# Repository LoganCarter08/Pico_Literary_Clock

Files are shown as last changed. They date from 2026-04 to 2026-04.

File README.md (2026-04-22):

# DIY Literary Clock Running on a Raspberry Pi Pico W

Display a book quote for each minute of the day!

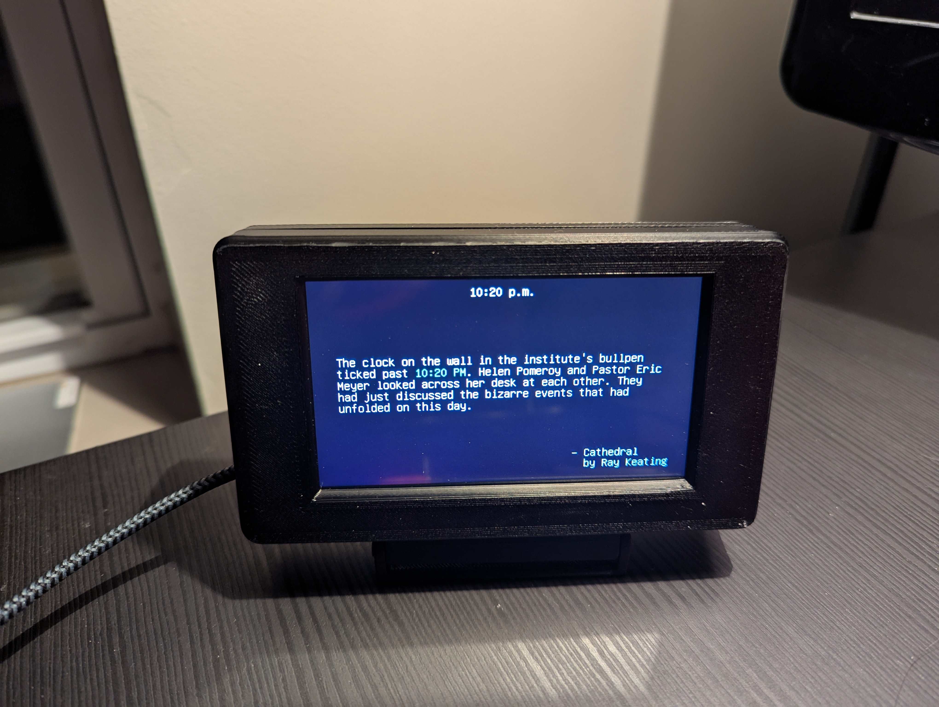
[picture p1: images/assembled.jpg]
on image

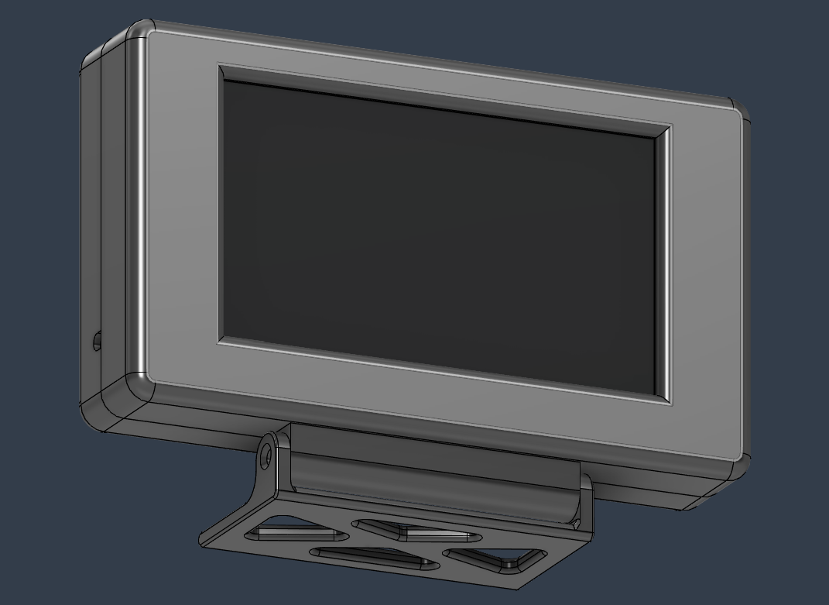
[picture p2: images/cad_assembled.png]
cad assembled


Quotes (litclock_annotated.csv) were sourced from https://github.com/JohannesNE/literature-clock/tree/master

## Hardware and Tools Required:

1. Pico Pi 2 W. Likely a Pico Pi W would work, but I have only tested a 2. A W model is needed for a wifi connection.
2. A display. [This one](https://www.buydisplay.com/4-3-inch-tft-lcd-display-capacitive-touchscreen-ra8875-controller) was used. A touchscreen version was selected for this, but they likely have cheaper ones without touchscreen capabilities.
   1. If you use the one linked I used the following configuration:
      1. Interface: Pin Header Connection-4-Wire SPI
      2. Power Supply: VDD=5.0V
      3. Font Chip: ER3301-1
   2. If you use a different one you will need to modify the 3D models and likely the code

3. 3D printer or ability to get 3D printed parts
4. Soldering iron
5. Solder
6. Wire
7. Wire Strippers
8. [3mm x 20mm flat chamfer headed bolts](https://www.amazon.com/Hoomuy-100pcs-Socket-Countersunk-Threaded/dp/B0GDWH9DZK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)
9. [3mm x 8mm flat chamfer headed bolts](https://www.amazon.com/DTGN-M3-0-5x8mm-Socket-Screws-Countersunk/dp/B0CQ1VJTMK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)
10. [3mm threaded heat inserts](https://www.amazon.com/Ktehloy-Threaded-Printing-Components-M3x4x5mm/dp/B0CLKCQ2SH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)
11. [2mm x 6mm bolts](https://www.amazon.com/M2-0-4-Socket-Machine-Countersunk-Quantity/dp/B0CG1SXGCN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)
12. [2mm nuts](https://www.amazon.com/pouilzx-Carbon-Steel-Hexagon-200pcs/dp/B0CMG7Q27P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)
13. Micro USB cable
14. USB power supply. Must match the other end of the micro USB cable.

## Software Instructions:

1. [Configure your Pico](https://learn.adafruit.com/getting-started-with-raspberry-pi-pico-circuitpython/circuitpython) to use CircuitPython. Be sure to select the correct uf2 file for your board. The link in the guide will just take you to the original Pico.
1. Go to [Adafruit](https://accounts.adafruit.com/) and create an account.
1. Sign into [Adafruit IO](io.adafruit.com) with your Adafruit account.
1. Click My Key on the top bar.
1. Open circuit_python_files/settings.toml
1. Replace ADAFRUIT_AIO_USERNAME and ADAFRUIT_AIO_KEY with your Adafruit account details.
1. Use the [TZ identifier values on Wikipedia](https://en.wikipedia.org/wiki/List_of_tz_database_time_zones) to set your timezone.
1. Set CIRCUITPY_WIFI_SSID as your wifi name.
1. Set CIRCUITPY_WIFI_PASSWORD as your wifi password.
1. Change the rest of the settings in settings.toml to match your preferences. Descriptions of each setting can be found below.

   Note: Some sample colors are provided. More can be added within the COLORS dict in code.py. They are in RGB format and can be modified or more can be added for your needs.

1. Make sure you have Python installed on your computer. Latest version is recommended.
1. Open a terminal and navigate to the folder containing these files and run `python .\csv_to_json.py`
1. Make sure Circuit Python is installed on your Pico Pi
1. Connect your Pico to your computer
1. Upload the contents of circuit_python_files to your Pico. This will take a while.

## settings.toml

The following settings are for you to be able to configure certain parts of the display without changing actual code.

| Setting | Description | Accepted Values/Type |
| --- | --- | --- |
| CIRCUITPY_WIFI_SSID | Name of your wifi. | String |
| CIRCUITPY_WIFI_PASSWORD | Password for your wifi | String |
| ADAFRUIT_AIO_USERNAME | Username for your Adafruit AIO account. | String |
| ADAFRUIT_AIO_KEY | Access key for your Adafruit AIO account. | String |
| TIMEZONE | Timezone you live in. [List of timezones.](https://en.wikipedia.org/wiki/List_of_tz_database_time_zones) | String |
| DISPLAY_MERIDIEM | Display a.m. or p.m. in the time at the top of the screen. Is not applied if using military time. | String as "true" or "false" |
| USE_MILITARY_TIME | Display time at the top of the screen in military time instead of 12 hour. | String as "true" or "false" |
| SCREEN_OFF_TIME | Time the screen should turn off. This will save power and increase the lifespan of your screen. | String of array in format of "[hour, minute]" |
| SCREEN_ON_TIME | Time the screen should turn on. | String of array in format of "[hour, minutes]" |
| BACKGROUND_COLOR | Color to choose for the background of the screen. | String options: "BLACK", "RED", "BLUE", "GREEN", "YELLOW", "CYAN", "MAGENTA", "WHITE" |
| TEXT_COLOR | Color for any text that is not the time of day in the quote. | String options: "BLACK", "RED", "BLUE", "GREEN", "YELLOW", "CYAN", "MAGENTA", "WHITE" |
| HIGHLIGHT_COLOR | Color for the time in the quote. | String options: "BLACK", "RED", "BLUE", "GREEN", "YELLOW", "CYAN", "MAGENTA", "WHITE" |

## Assembly Instructions:

1. Print all of the pieces in the 3d_model_files folder
2. Add the heat insert threads into each of the 4 corners of the front piece
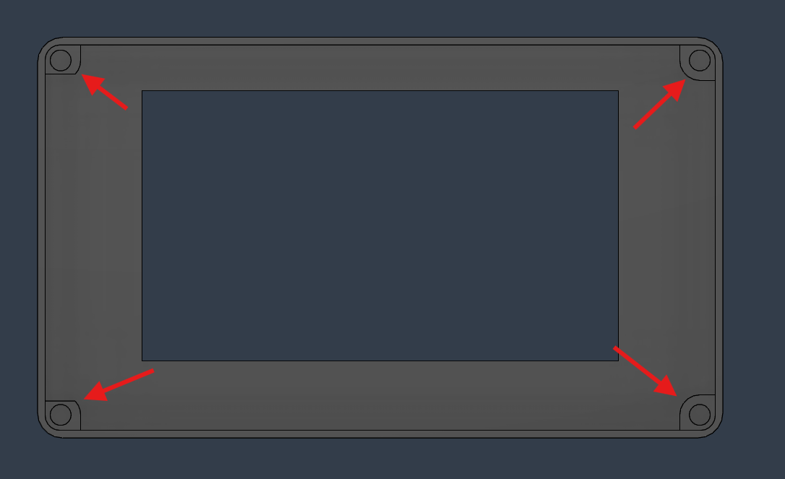
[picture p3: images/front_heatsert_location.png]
front heatsert locations
   
3. Heat insert threads into all 4 holes on the base mount
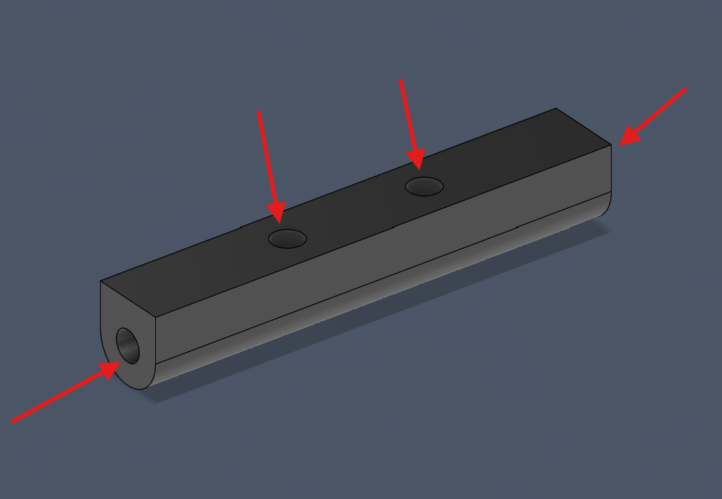
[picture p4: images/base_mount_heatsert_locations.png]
base heatsert locations
   
4. Sand down the corners of the screen to fit in the 3D printed case. The corners just need to be rounded to match the metal around the mounting hole.
5. Bolt the base mount to the front cover.
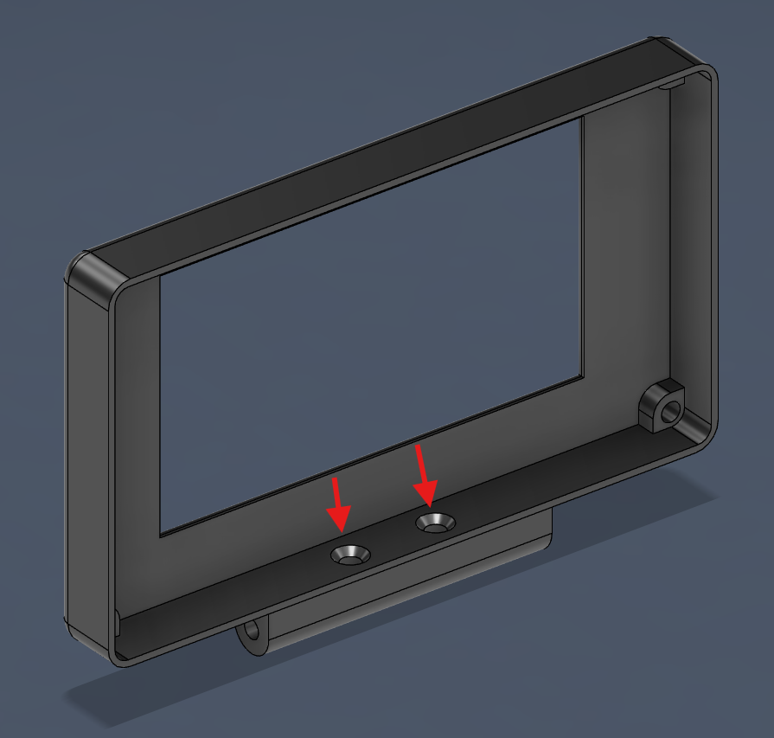
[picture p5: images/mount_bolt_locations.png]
base to front bolt locations
   
6. Insert the screen into the front cover.
7. Bolt the pico onto the pi mount piece using 4 M2 bolts and nuts. The pico should go on the smooth side of the plate. The side with the offset feet will sit on the screen. The Pico's USB port should face away from the GPIO pins on the screen.
8. Sit the pi mount plate onto the screen so that the 4 holes align.
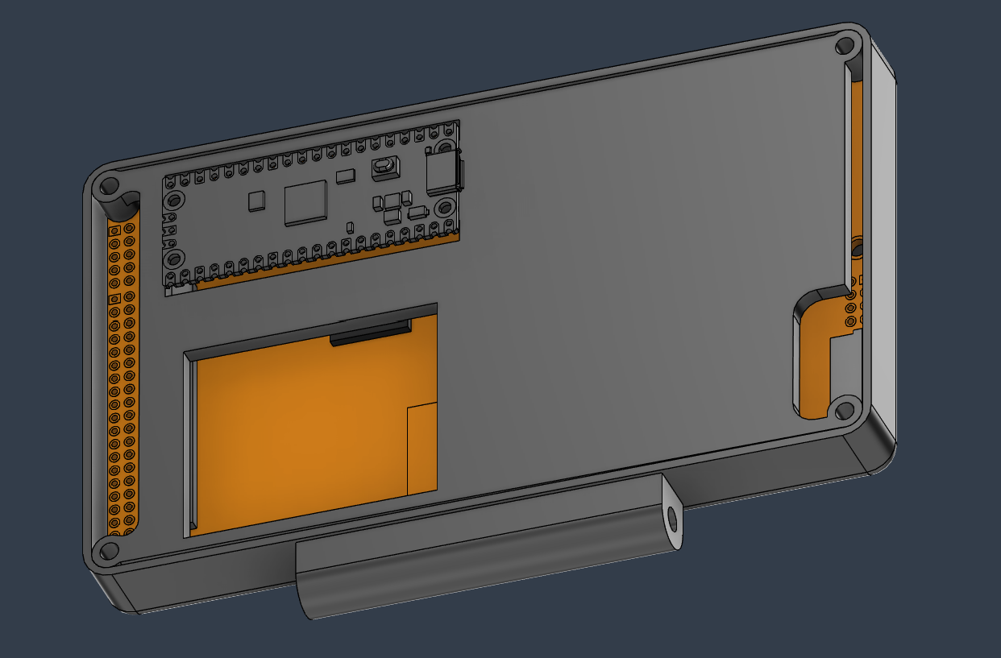
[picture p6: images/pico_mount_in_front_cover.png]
pico in front cover
   
9. Solder wires from the pi to the screen. Pinout information can be found below.
10. Plug the USB cable into the pi
11. Sit the back cover over the pi and screen where the slot in the cover allows for the USB cable to exit the bottom left (left when viewing from the front) of the case
12. Bolt the base plate onto the base mount and snug the screws when the desired any is set
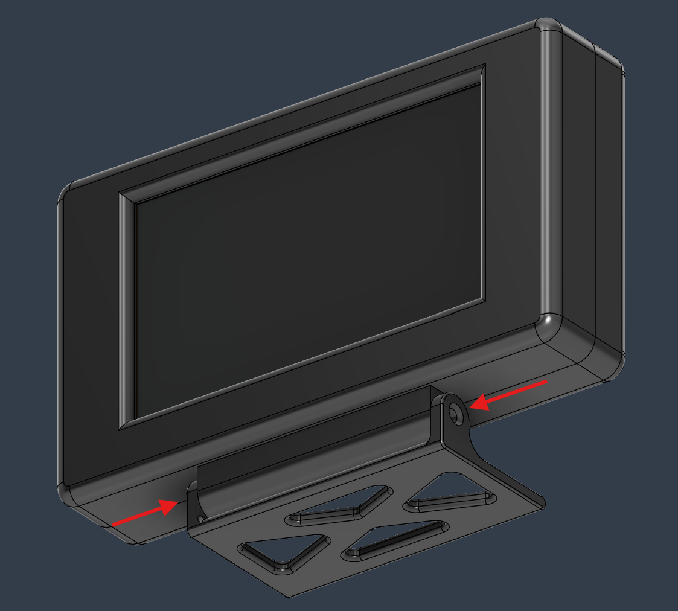
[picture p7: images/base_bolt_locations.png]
base plate bolt locations
    
13. Plug the USB cable into the power supply and wait for the screen to startup. This may take a few seconds depending on how quickly it can connect to your network.

## Pinouts:

[Screen doc with pin locations](https://www.buydisplay.com/download/manual/ER-TFTM043A2-3_Datasheet.pdf).

| Pico Pin | Screen Pin # | Description |
| --- | --- | --- |
| GP21 | 5 | CS |
| GP22 | 11 | Reset |
| GP1 | 10 | Int |
| GP18 | 8 | SCLK |
| GP19 | 7 | Pico MOSI |
| GP16 | 6 | Pico MISO |

## Other Notes:

- Other microcontroller boards than the Pico Pi W can be used. The 3D models will need updated and likely some code changes to support the correct pinout. You will also be limited to storage space as the quote files take up a lot of space.
- A Pico W is required because the device needs to connect to the internet to keep the clock synchronized as there tends to be some time drift relying on internal time keeping.
- If you want to add/edit/delete any quotes you can edit the litclock_annotated.csv file, delete the quotes off the pico, and then load the new quotes from the circuit_python_files/lib/quotes folder. Otherwise you may get errors about not enough storage space.
- A few times of the day currently do not have quotes. If you find any please feel free to let me know and I can update the file with them. Current 11:46, 12:31, 13:36, and 18:44 are missing.

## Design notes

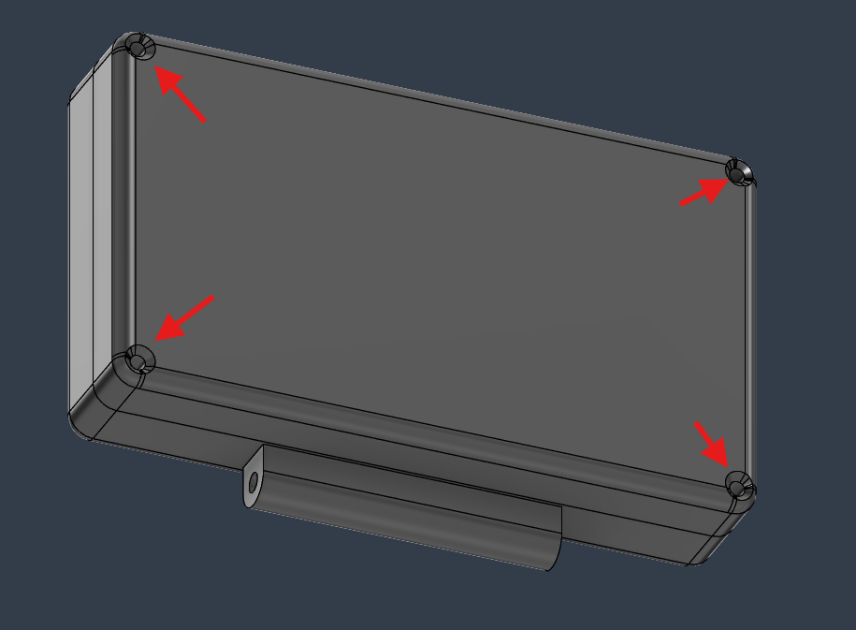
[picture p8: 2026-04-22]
images/back_cover_bolt_locations.png

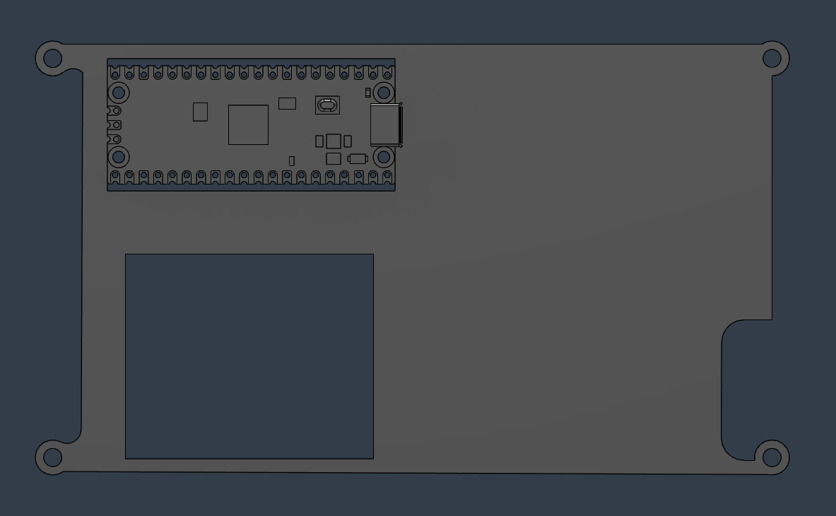
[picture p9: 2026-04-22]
images/pico_mount_orientation.png

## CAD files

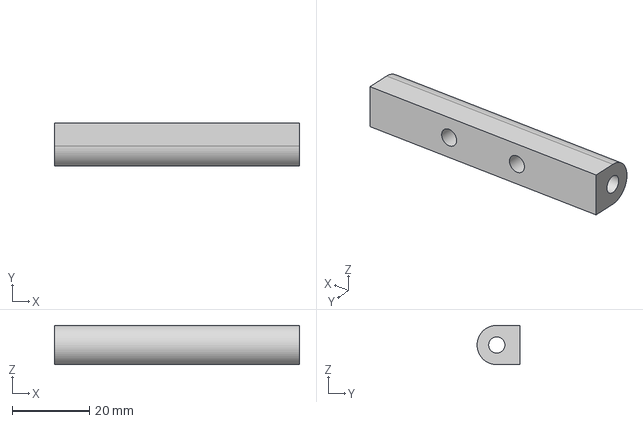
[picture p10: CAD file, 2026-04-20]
3d_model_files/base_mount.step
63.5 x 11.1 x 10.2 mm

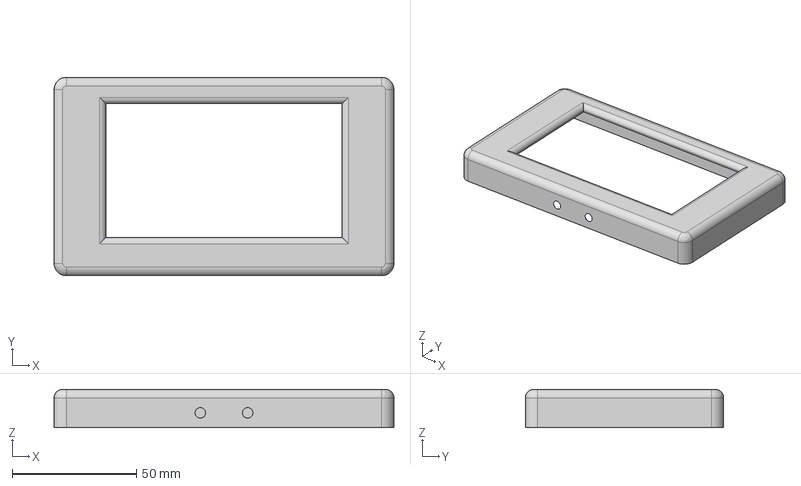
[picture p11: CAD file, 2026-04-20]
3d_model_files/front.step
136.7 x 79.8 x 15.4 mm

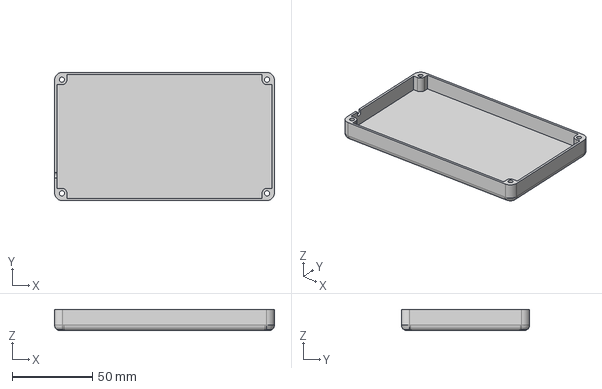
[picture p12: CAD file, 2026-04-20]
3d_model_files/back.step
136.7 x 79.8 x 13.2 mm

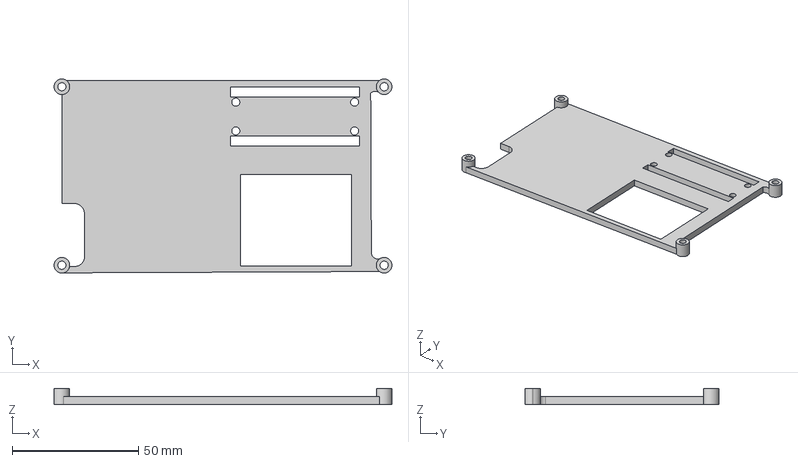
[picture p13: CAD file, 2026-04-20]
3d_model_files/pi_mount.step
133.7 x 76.8 x 6.35 mm

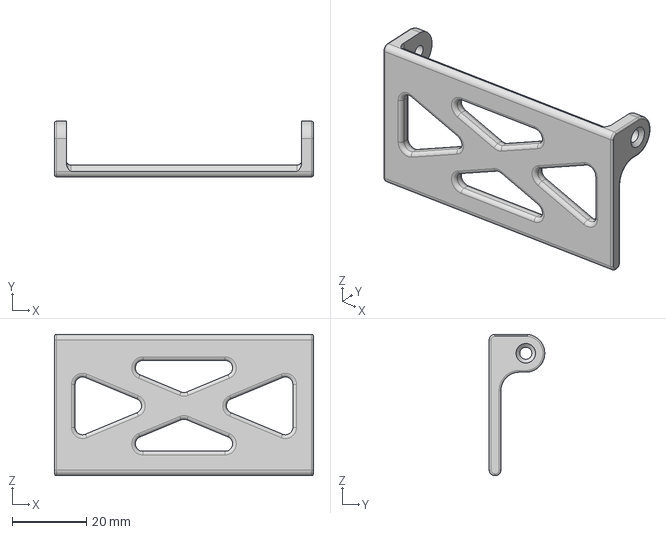
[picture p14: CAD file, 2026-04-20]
3d_model_files/base_plate.step
69.9 x 15.0 x 38.1 mm

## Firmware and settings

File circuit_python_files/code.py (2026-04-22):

import ipaddress
import os
import ssl
import wifi
import socketpool
import adafruit_requests
import time
import gc
import sys
import random
import math
import time
import board
import busio
import digitalio
from adafruit_ra8875 import ra8875
from adafruit_ra8875.ra8875 import color565
import supervisor
import json

COLORS = {
    "BLACK": color565(10, 0, 0),
    "RED": color565(255, 0, 0),
    "BLUE": color565(0, 0, 255),
    "GREEN": color565(0, 255, 0),
    "YELLOW": color565(255, 255, 0),
    "CYAN": color565(0, 255, 255),
    "MAGENTA": color565(255, 0, 255),
    "WHITE": color565(255, 255, 255),
}

LINE_HEIGHT = 15
QUOTE_MARGIN = 30
AUTHOR_MARGIN = 15
AVERAGE_CHAR_WIDTH = 8
HIGHLIGHT_SPACING = 0
MAX_X = 470
MAX_Y = 270
MAX_LINE_CHAR_COUNT = math.floor((MAX_X - (QUOTE_MARGIN * 2)) / AVERAGE_CHAR_WIDTH) #51

BACKGROUND_COLOR = COLORS[os.getenv("BACKGROUND_COLOR")]
TEXT_COLOR = COLORS[os.getenv("TEXT_COLOR")]
HIGHLIGHT_COLOR = COLORS[os.getenv("HIGHLIGHT_COLOR")]
MISSING_QUOTES = ["11:46", "12:31", "13:36", "18:44"]

DISPLAY_MERIDIEM = os.getenv("DISPLAY_MERIDIEM").lower() == "true"
USE_MILITARY_TIME = os.getenv("USE_MILITARY_TIME").lower() == "true"

def timeToDecimal(time):
    return float(time[0]) + (float(time[1]) / 60)

SCREEN_OFF_TIME = timeToDecimal([int(x) for x in os.getenv("SCREEN_OFF_TIME").split(":")])
SCREEN_ON_TIME = timeToDecimal([int(x) for x in os.getenv("SCREEN_ON_TIME").split(":")])

# Configuration for CS and RST pins:
cs_pin = digitalio.DigitalInOut(board.GP21)
rst_pin = digitalio.DigitalInOut(board.GP22)
int_pin = digitalio.DigitalInOut(board.GP1)

# Config for display baudrate (default max is 6mhz):
BAUDRATE = 6000000

# Setup SPI bus using hardware SPI:
spi = busio.SPI(clock=board.GP18, MOSI=board.GP19, MISO=board.GP16)

# Create and setup the RA8875 display:
display = ra8875.RA8875(spi, cs=cs_pin, rst=rst_pin, baudrate=BAUDRATE)
display.init()

# lowering the brightness causes buzzing noises.
#display.brightness(200)


# Get our username, key and desired timezone
ssid = os.getenv("CIRCUITPY_WIFI_SSID")
password = os.getenv("CIRCUITPY_WIFI_PASSWORD")
aio_username = os.getenv("ADAFRUIT_AIO_USERNAME")
aio_key = os.getenv("ADAFRUIT_AIO_KEY")
timezone = os.getenv("TIMEZONE")
TIME_URL = f"https://io.adafruit.com/api/v2/{aio_username}/integrations/time/strftime?x-aio-key={aio_key}&tz={timezone}"
TIME_URL += "&fmt=%25Y-%25m-%25d+%25H%3A%25M%3A%25S.%25L+%25j+%25u+%25z+%25Z"


wifi.radio.stop_scanning_networks()
wifi.radio.connect(ssid, password)
print(f"Connected to {ssid}!")

pool = socketpool.SocketPool(wifi.radio)
requests = adafruit_requests.Session(pool, ssl.create_default_context())


def incTime(lastTime) -> int:
    minutes = int(lastTime[1]) + 1
    if minutes == 60:
        minutes = 0
        lastTime[0] = str(int(lastTime[0]) + 1)
    lastTime[1] = str(minutes) if minutes > 9 else "0" + str(minutes)
    if lastTime[0] == 24:
        lastTime[0] = 0
    return lastTime

def getRemoteTime() -> list[str]:
    gc.collect()
    try:
        if not wifi.radio.ipv4_address:
            wifi.radio.stop_scanning_networks()
            wifi.radio.connect(ssid, password)
        response = requests.get(TIME_URL)
        splitDate = response.text.split(" ")
        splitTime = splitDate[1].split(":")
        return splitTime
    except:
        return ["", ""]

def getTime(timesRan, lastTime) -> tuple[list[str], float, int]:
    # get time every half hour to make sure we haven't crept
    sleepTime = 60
    timesRan = timesRan + 1
    if timesRan >= 15:
        print("Queried internet for time")
        queriedTime = getRemoteTime()
        if queriedTime[0] == "":
            print("failed getting remote time")
            if lastTime[0] == "":
                #display.fill(BACKGROUND_COLOR)
                #display.txt_set_cursor(100, math.floor(MAX_Y / 2))
                #display.txt_write("No internet connection")
                print("No internet connection")
                while queriedTime[0] == "":
                    queriedTime = getRemoteTime()
                    time.sleep(60)

            lastTime = incTime(lastTime)
        else:
            lastTime = queriedTime
            timesRan = 0
            sleepTime = 60 - float(lastTime[2])

    else:
        lastTime = incTime(lastTime)

    return lastTime, sleepTime, timesRan

def displayTime(lastTime) -> None:
    display.txt_trans(TEXT_COLOR)
    display.txt_size(0)
    time = ""

    hours = lastTime[0]
    if USE_MILITARY_TIME:
        time = hours + ":" + lastTime[1]
    else:
        meridiem = "a.m."
        if int(hours) == 0:
            hours = "12"
        elif int(hours) > 12:
            hours = str(int(hours) % 12)
            meridiem = "p.m."

        time = hours + ":" + lastTime[1] + (" " + meridiem if DISPLAY_MERIDIEM else "")

        if time[0] == "0":
            time = time[1:]

    display.txt_set_cursor(math.floor((MAX_X / 2) - ((AVERAGE_CHAR_WIDTH * len(time)) / 2)), 10)
    display.txt_write(time)

def checkIfReloadNeeded(time):
    if time not in MISSING_QUOTES:
        # This is a goofy solution, but after running for a long time
        # circuitpython seems to lose the ability to find files.
        # It will not throw an error, it just can't find them anymore.
        # if that happens, force a reload.
        print("Reloading")
        supervisor.reload()
    else:
        print("Quote is known as missing")

def getQuote(lastTime) -> None:
    quote = {
        "fullQuote": "No quote found for this time :( I'm sorry",
        "highlight": "I'm sorry",
        "book": "No book found",
        "author": ""
    }

    quotePath = "lib/quotes/" + lastTime[0] + "_" + lastTime[1] + ".json"
    try:
        # this will throw an OSError if path doesn't exist
        os.stat(quotePath)

        with open(quotePath, "r") as file:
            data = json.load(file)
            randQuoteInd = random.randint(0, len(data) - 1)
            quote = data[randQuoteInd]

    except OSError:
        # os.stat is kind of a dumb way to do this in circuitpython because
        # it just throws an error if the file isn't found.
        checkIfReloadNeeded(lastTime[0] + ":" + lastTime[1])
    except Exception as e:
        print(lastTime)
        print(e)
        quote["book"] = str(e)

    return quote

def splitQuote(quote) -> tuple[list[str], int, int]:
    REPLACE_STR = "%&%"
    quote["fullQuote"] = quote["fullQuote"].replace(quote["highlight"], REPLACE_STR)
    forcedLines = []

    highlightIndex = []
    highlightSubIndex = []
    tempChars = ""
    skipCount = 0
    addHighlight = False
    for i in range(len(quote["fullQuote"])):
        added = False

        if skipCount > 0:
            skipCount = skipCount - 1
        elif i < len(quote["fullQuote"]) - 3 and quote["fullQuote"][i : i + 4].lower() == "<br>":
            skipCount = 3
            added = True
        elif i < len(quote["fullQuote"]) - (len(REPLACE_STR) - 1) and quote["fullQuote"][i : i + len(REPLACE_STR)] == REPLACE_STR:
            skipCount = len(REPLACE_STR) - 1
            addHighlight = True
        elif quote["fullQuote"][i] == " ":
            nextSpace = -1
            for j in range(i + 1, len(quote["fullQuote"])):
                found = False
                if quote["fullQuote"][j] == " ":
                    found = True
                elif quote["fullQuote"][j] == "<" and j + 3 <= len(quote["fullQuote"]) - 1 and quote["fullQuote"][j : j + 4] == "<br>":
                    found = True

                # I think this needs to handle the case if REPLACE_STR was found while getting next space
                # to know the full length, but right now it is working and I don't think it should be.
                if found:
                    nextSpace = j - i
                    break
            if len(tempChars) + nextSpace > MAX_LINE_CHAR_COUNT or (nextSpace == -1 and len(tempChars) + len(quote["fullQuote"]) - i > MAX_LINE_CHAR_COUNT):
                added = True
            elif len(tempChars) > 0:
                tempChars = tempChars + " "
        else:
            tempChars = tempChars + quote["fullQuote"][i]

        if added and len(tempChars) > 0:
            forcedLines.append(tempChars)
            tempChars = ""

        if addHighlight:
            # if we can't fit it in this line then add to forcedLines
            if len(tempChars) + len(quote["highlight"]) + HIGHLIGHT_SPACING > MAX_LINE_CHAR_COUNT:
                forcedLines.append(tempChars)
                tempChars = ""

            highlightIndex.append(len(forcedLines))
            highlightSubIndex.append(len(tempChars) + math.floor(HIGHLIGHT_SPACING / 2))

            for j in range(len(quote["highlight"]) + HIGHLIGHT_SPACING):
                tempChars = tempChars + " "

            #forcedLines.append(quote["highlight"])
            addHighlight = False

    if len(tempChars) == 1:
        forcedLines[len(forcedLines) - 1] = forcedLines[len(forcedLines) - 1] + tempChars
    else:
        forcedLines.append(tempChars)

    return forcedLines, highlightIndex, highlightSubIndex


def displaySource(quote, lineLength) -> None:
    author = "by " + quote["author"]
    authorWidth = len(author) * AVERAGE_CHAR_WIDTH

    title = "- " + quote["book"]

    maxSourceCharWidth = math.floor((MAX_X - (2 * AUTHOR_MARGIN)) / AVERAGE_CHAR_WIDTH)

    if lineLength < 13:
        if len(title) >= maxSourceCharWidth:
            title = title[: maxSourceCharWidth - 3] + "..."

        titleWidth = len(title) * AVERAGE_CHAR_WIDTH

        titleX = math.floor(MAX_X - AUTHOR_MARGIN - titleWidth)
        authorX = math.floor(MAX_X - AUTHOR_MARGIN - authorWidth - (2 * AVERAGE_CHAR_WIDTH))

        authorTitleCombX = max(AUTHOR_MARGIN, min(titleX, authorX))

        display.txt_set_cursor(authorTitleCombX, math.floor(MAX_Y - (LINE_HEIGHT * 2) - AUTHOR_MARGIN))
        display.txt_write(title)
        display.txt_set_cursor(authorTitleCombX + (2 * AVERAGE_CHAR_WIDTH), math.floor(MAX_Y - LINE_HEIGHT - AUTHOR_MARGIN))
        if author != "":
            display.txt_write(author)
    else:
        combo = title + " " + author
        if len(combo) >= maxSourceCharWidth:
            combo = title[: maxSourceCharWidth - len(author) - 4] + "... " + author

        comboWidth = len(combo) * AVERAGE_CHAR_WIDTH

        comboX = max(0, math.floor(MAX_X - AUTHOR_MARGIN - comboWidth))
        display.txt_set_cursor(comboX, math.floor(MAX_Y - LINE_HEIGHT - AUTHOR_MARGIN))
        display.txt_write(combo)

def displayQuote(lastTime) -> None:
    quote = getQuote(lastTime)

    print("-" * 40)
    print(lastTime[0] + ":" + lastTime[1])
    print(quote["fullQuote"])
    print("-" * 40)

    forcedLines, highlightIndex, highlightSubIndex = splitQuote(quote)

    tempLineHeight = LINE_HEIGHT if len(forcedLines) < 13 else 14

    topPos = math.floor(MAX_Y / 2) - (len(forcedLines) / 2) * tempLineHeight

    for index, line in enumerate(forcedLines):
        display.txt_set_cursor(QUOTE_MARGIN, math.floor(topPos + (tempLineHeight * index)))
        if index in highlightIndex:
            display.txt_set_cursor(QUOTE_MARGIN, math.floor(topPos + (tempLineHeight * index)))
            display.txt_write(line)
        else:
            display.txt_write(line)

    for i in range(len(highlightIndex)):
        display.txt_trans(HIGHLIGHT_COLOR)
        display.txt_set_cursor(QUOTE_MARGIN + math.floor(highlightSubIndex[i] * AVERAGE_CHAR_WIDTH), math.floor(topPos + (tempLineHeight * highlightIndex[i])))
        display.txt_write(quote["highlight"])
        display.txt_trans(TEXT_COLOR)

    displaySource(quote, len(forcedLines))

def screenOn(lastTime) -> bool:
    decimalCurrentTime = timeToDecimal(lastTime)
        
    # handle case of over midnight off 
    if SCREEN_ON_TIME < SCREEN_OFF_TIME:
        # between off time and midnight, so turn off 
        if (decimalCurrentTime >= SCREEN_OFF_TIME and decimalCurrentTime < 23.99999) or (decimalCurrentTime < SCREEN_ON_TIME): 
            return False 
        return True
    elif (decimalCurrentTime >= SCREEN_OFF_TIME):
        if (decimalCurrentTime >= SCREEN_ON_TIME):
            return True
        return False 
    return True 

timesRan = 61
lastTime = ["", ""]
lastScreenState = True
while True:
    display.fill_rect(0, 0, MAX_X + 20, MAX_Y + 20, BACKGROUND_COLOR)

    lastTime, sleepTime, timesRan = getTime(timesRan, lastTime)

    if not screenOn(lastTime):
        if lastScreenState:
            lastScreenState = False
            display.brightness(0)
            display.turn_on(False)
        print("Sleeping: ", sleepTime, " - ", lastTime)
        time.sleep(sleepTime)
        continue
    elif not lastScreenState:
        lastScreenState = True
        display.turn_on(True)
        display.brightness(255)

    displayTime(lastTime)
    displayQuote(lastTime)

    time.sleep(sleepTime)

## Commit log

2026-04-20 init commit
    [back.step, base_mount.step, base_plate.step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]
2026-04-20 removing extra 3d model and changing default quote
    [front.stl]
2026-04-20 updating readme, handling longer book and author titles, fixing some issues in the quotes with non ascii characters, and making all breaks be the same
    [litclock_annotated.csv]
2026-04-21 fixing screen on and off to allow for minutes and handling title overflow better
    [code.py]
2026-04-21 updating readme with some initial assembly instructions and a few cleanups in the code.py
